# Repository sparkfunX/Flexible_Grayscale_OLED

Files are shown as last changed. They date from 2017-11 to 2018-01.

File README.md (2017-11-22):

SparkFun Carrier Board for Flexible Grayscale OLED Display
========================================

SparkFun Flexible Grayscale Carrier Board

[*SparkFun Flexible Grayscale Display - 1.81" (SPX-14543)*](https://www.sparkfun.com/products/14543)

This is a small flexible, grayscale OLED display. That’s right, we said flexible. We’ve been hearing about flexible displays for years, it’s finally here! You can’t fold it like paper but this OLED from Wisechip can be bent to a 40mm radius without damage. The display is than 0.5mm thick, less than 0.5 grams, and can display some impressive graphics with great contrast.

The carrier board generates the 12V required to drive the OLED display. The carrier board also has a signal buffer so that you can drive the display from any 3.3V or 5V microcontroller. However, because of the nature of the TXB0104 you must power the board with 3.5V or more. Your microcontroller can be 3.3V or 5V but we recommend you power the carrier board with 5V.

Repository Contents
-------------------

* **/Hardware** - Eagle design files (.brd, .sch)

Library
--------------
* **[Arduino Library](https://github.com/sparkfun/SparkFun_SSD1320_OLED_Arduino_Library)** - Library for drawing, graphics, text, etc.

License Information
-------------------

This product is _**open source**_! 

Please review the LICENSE.md file for license information. 

If you have any questions or concerns on licensing, please contact techsupport@sparkfun.com.

Please use, reuse, and modify these files as you see fit. Please maintain attribution to SparkFun Electronics and release anyThing Development Board derivative under the same license.

Distributed as-is; no warranty is given.

- Your friends at SparkFun.

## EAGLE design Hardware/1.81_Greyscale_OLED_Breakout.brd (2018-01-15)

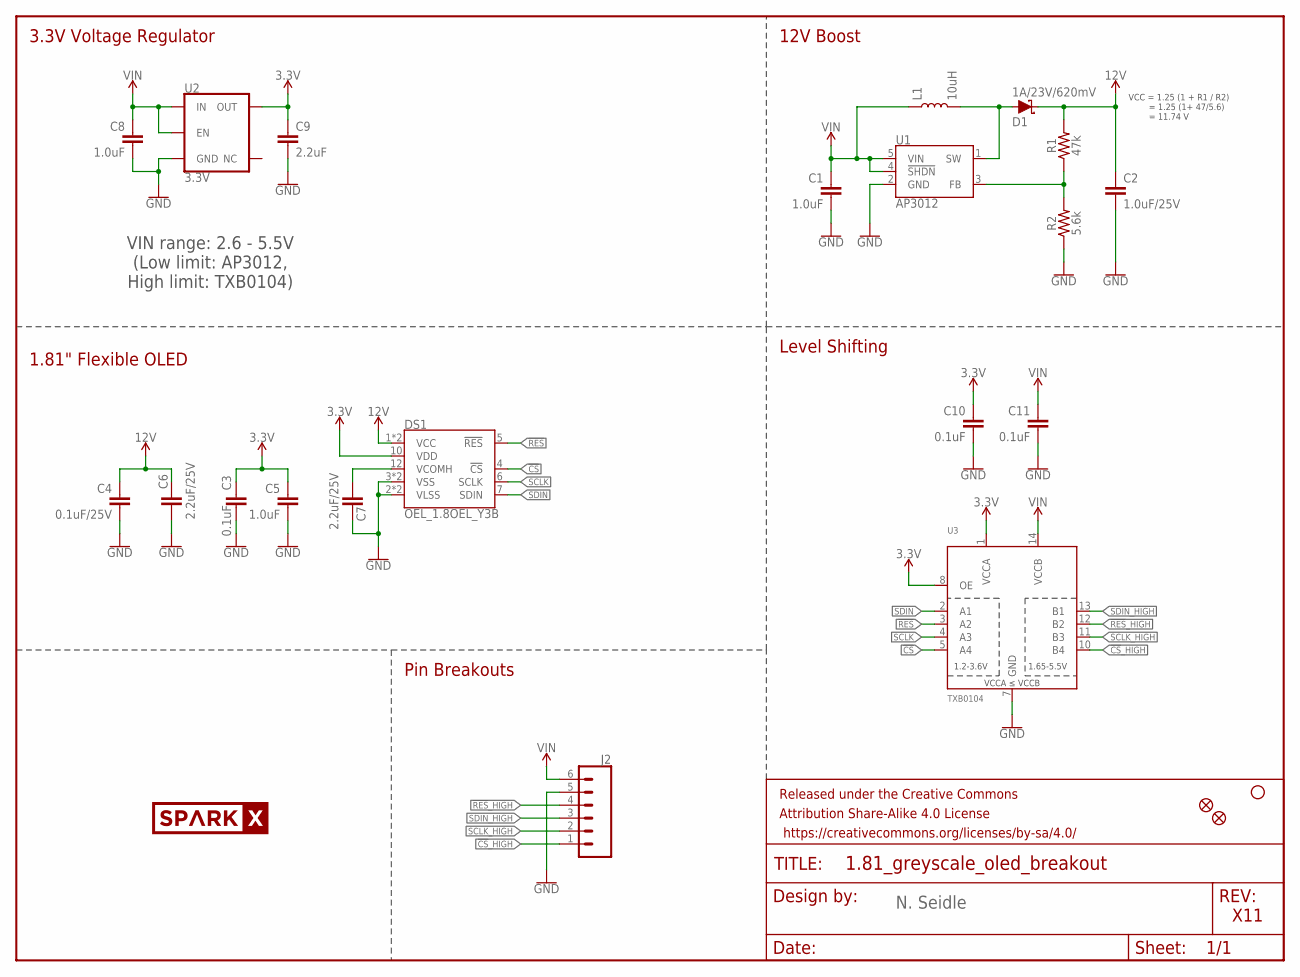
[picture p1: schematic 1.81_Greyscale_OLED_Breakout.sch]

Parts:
C1, C5, C8: 1.0uF; 0603
C2: 1.0uF/25V; 0805
C3, C10, C11: 0.1uF; 0603
C4: 0.1uF/25V; 0603
C6, C7: 2.2uF/25V; 0805
C9: 2.2uF; 0603
D1: 1A/23V/620mV; SOD-323
DS1: OEL_1.8OEL_Y3B; OEL_1.8_FPC_Y3B
FD1, FD2: FIDUCIAL1X2; FIDUCIAL-1X2
FRAME1: FRAME-LETTER; CREATIVE_COMMONS
H2: STAND-OFF
J2: CONN_06NO_SILK_NO_POP; 1X06_NO_SILK
L1: 10uH; INDUCTOR_3X3
LOGO1: SPARKX-LOGO5; SPARKX-LARGE
R1: 47k; 0603
R2: 5.6k; 0603
U1: AP3012; SOT23-5
U2: 3.3V; SOT23-5
U3: TXB0104; SO14

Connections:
3.3V: C3.1, C5.1, C9.1, C10.1, DS1.10 (VDD), U2.5 (OUT), U3.1 (VCCA), U3.8 (OE)
12V: C2.1, C4.1, C6.1, D1.C, DS1.1 (VCC), DS1.13 (VCC), R1.2
!CS!: DS1.4 (!CS!), U3.5 (A4)
!CS!_HIGH: J2.1, U3.10 (B4)
!RES!: DS1.5 (!RES!), U3.3 (A2)
!RES!_HIGH: J2.4, U3.12 (B2)
GND: C1.2, C2.2, C3.2, C4.2, C5.2, C6.2, C7.1, C8.2, C9.2, C10.2, C11.2, DS1.2 (VLSS), DS1.3 (VSS), DS1.8 (VSS), DS1.9 (VLSS), J2.5, R2.1, U1.2 (GND), U2.2 (GND), U3.7 (GND)
unnamed: C7.2, DS1.12 (VCOMH)
unnamed: D1.A, L1.P$2 (2), U1.1 (SW)
unnamed: R1.1, R2.2, U1.3 (FB)
SCLK: DS1.6 (SCLK), U3.4 (A3)
SCLK_HIGH: J2.2, U3.11 (B3)
SDIN: DS1.7 (SDIN), U3.2 (A1)
SDIN_HIGH: J2.3, U3.13 (B1)
VIN: C1.1, C8.1, C11.1, J2.6, L1.P$1 (1), U1.4 (!SHDN!), U1.5 (VIN), U2.1 (IN), U2.3 (EN), U3.14 (VCCB)

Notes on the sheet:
VCC = 1.25 (1 + R1 / R2) = 1.25 (1+ 47/5.6) = 11.74 V
VIN range: 2.6 - 5.5V (Low limit: AP3012, High limit: TXB0104)
3.3V Voltage Regulator
12V Boost
1.81" Flexible OLED
Level Shifting
Pin Breakouts
X11
N. Seidle

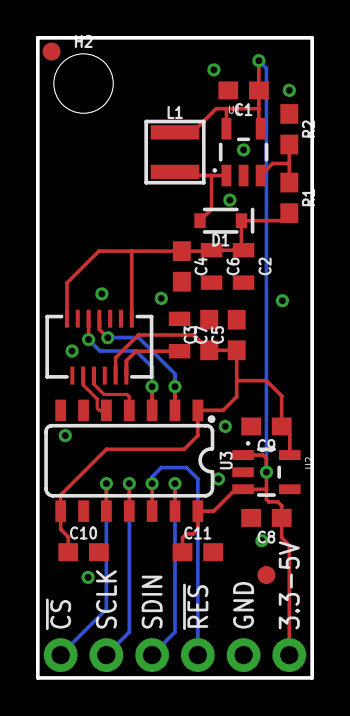
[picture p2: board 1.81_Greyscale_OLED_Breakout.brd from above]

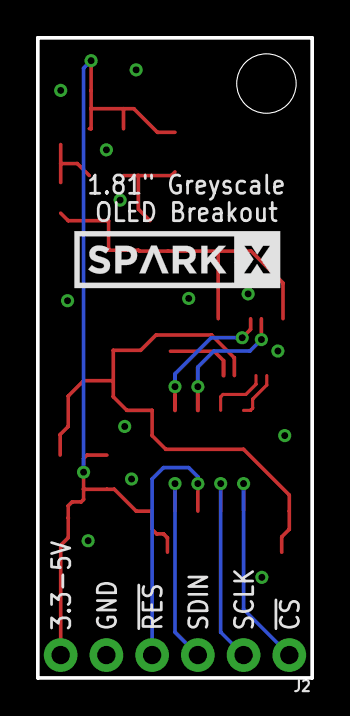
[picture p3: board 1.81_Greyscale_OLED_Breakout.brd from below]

Board: 2 copper layers, 15.2 x 35.6 mm, 25 parts (3 on the bottom side), 15 nets.

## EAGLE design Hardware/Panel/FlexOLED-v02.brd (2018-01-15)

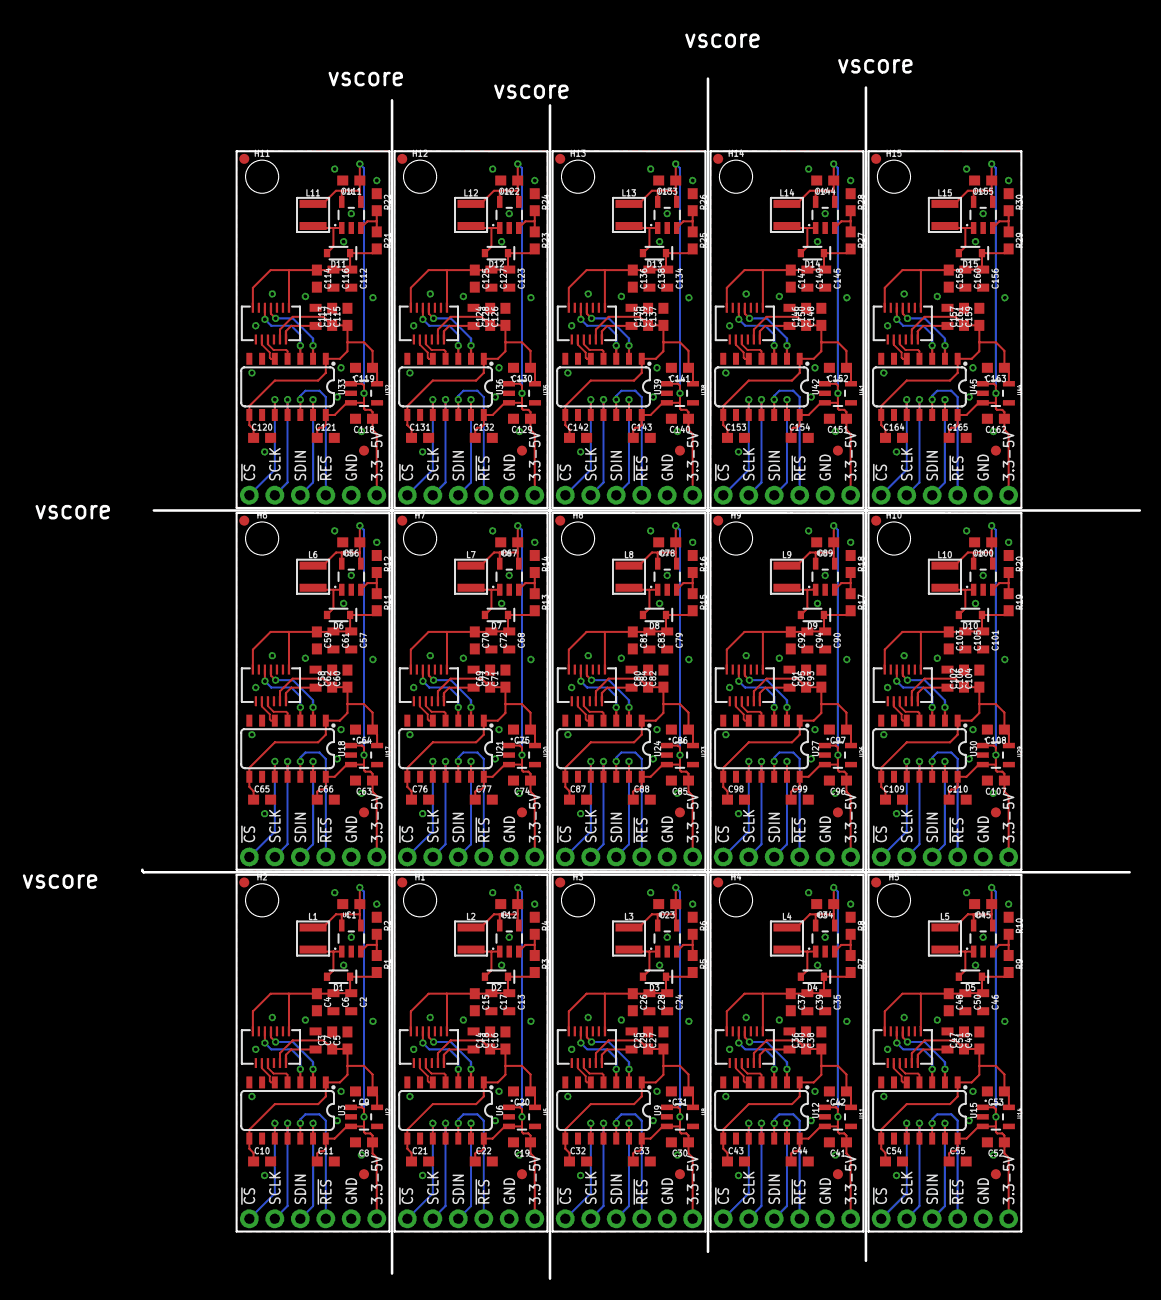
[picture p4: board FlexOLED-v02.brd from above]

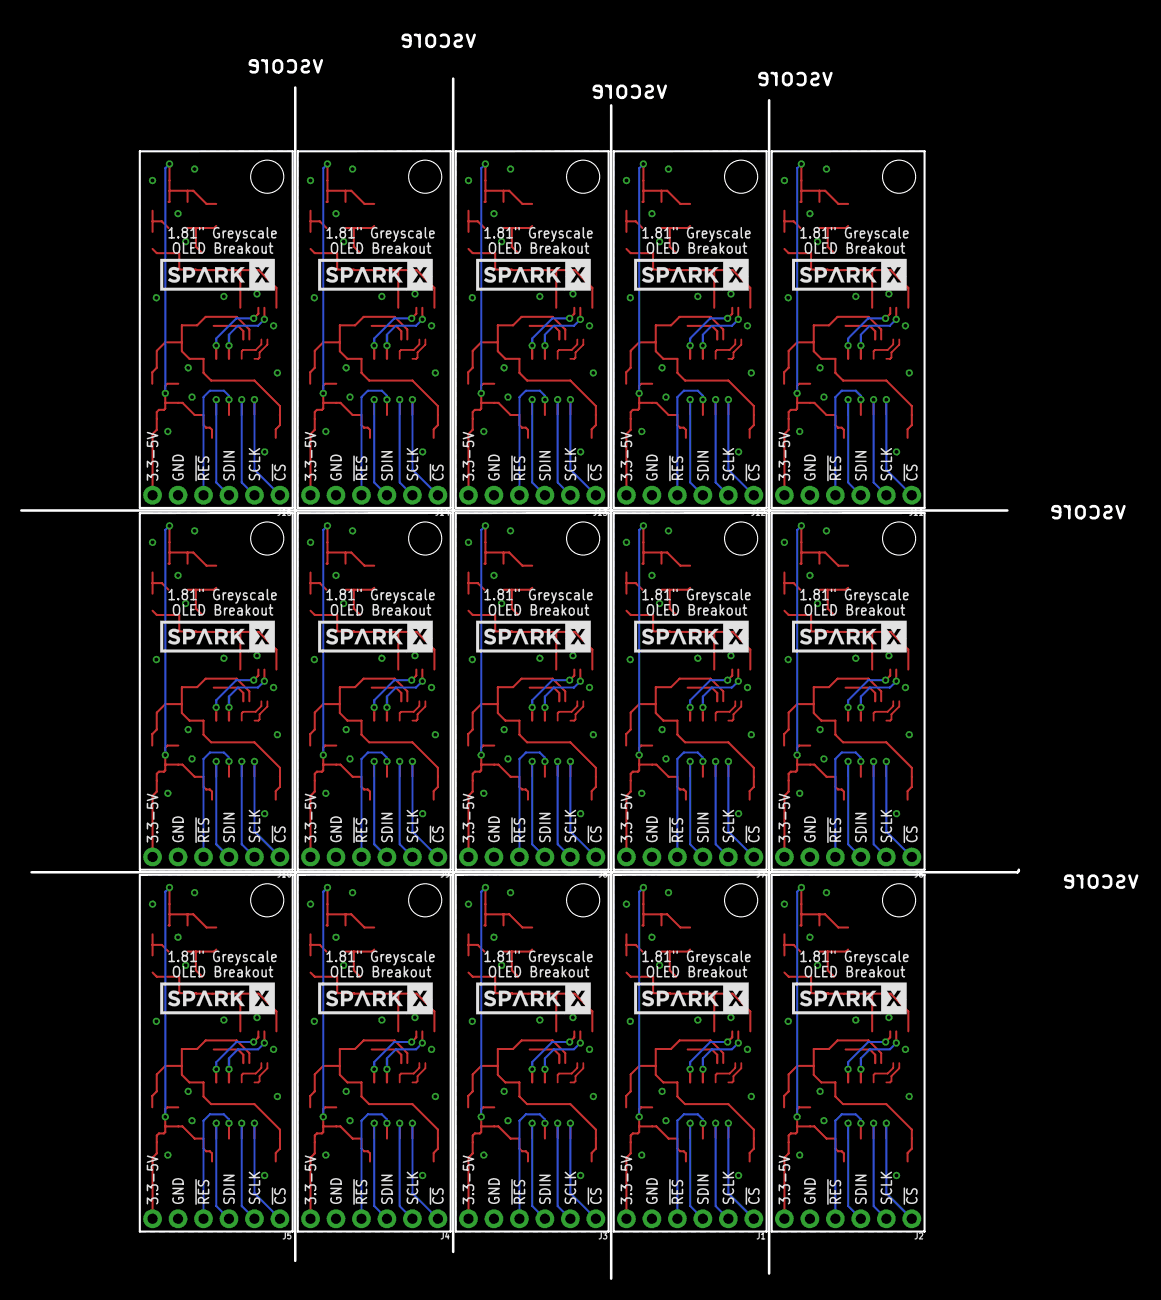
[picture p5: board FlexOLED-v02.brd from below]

Board: 2 copper layers, 99.4 x 119.6 mm, 360 parts (45 on the bottom side), 225 nets.

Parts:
C1, C5, C8, C12, C16, C19, C23, C27, C30, C34, C38, C41, C45, C49, C52, C56, C60, C63, C67, C71, C74, C78, C82, C85, C89, C93, C96, C100, C104, C107, C111, C115, C118, C122, C126, C129, C133, C137, C140, C144, C148, C151, C155, C159, C162: 1.0uF; 0603
C2, C13, C24, C35, C46, C57, C68, C79, C90, C101, C112, C123, C134, C145, C156: 1.0uF/25V; 0805
C3, C10, C11, C14, C21, C22, C25, C32, C33, C36, C43, C44, C47, C54, C55, C58, C65, C66, C69, C76, C77, C80, C87, C88, C91, C98, C99, C102, C109, C110, C113, C120, C121, C124, C131, C132, C135, C142, C143, C146, C153, C154, C157, C164, C165: 0.1uF; 0603
C4, C15, C26, C37, C48, C59, C70, C81, C92, C103, C114, C125, C136, C147, C158: 0.1uF/25V; 0603
C6, C7, C17, C18, C28, C29, C39, C40, C50, C51, C61, C62, C72, C73, C83, C84, C94, C95, C105, C106, C116, C117, C127, C128, C138, C139, C149, C150, C160, C161: 2.2uF/25V; 0805
C9, C20, C31, C42, C53, C64, C75, C86, C97, C108, C119, C130, C141, C152, C163: 2.2uF; 0603
D1, D2, D3, D4, D5, D6, D7, D8, D9, D10, D11, D12, D13, D14, D15: 1A/23V/620mV; SOD-323
DS1, DS2, DS3, DS4, DS5, DS6, DS7, DS8, DS9, DS10, DS11, DS12, DS13, DS14, DS15: OEL_1.8OEL_Y3B; OEL_1.8_FPC_Y3B
FD1, FD2, FD3, FD4, FD5, FD6, FD7, FD8, FD9, FD10, FD11, FD12, FD13, FD14, FD15, FD16, FD17, FD18, FD19, FD20, FD21, FD22, FD23, FD24, FD25, FD26, FD27, FD28, FD29, FD30: FIDUCIAL1X2; FIDUCIAL-1X2
H1, H2, H3, H4, H5, H6, H7, H8, H9, H10, H11, H12, H13, H14, H15: STAND-OFF
J1, J2, J3, J4, J5, J6, J7, J8, J9, J10, J11, J12, J13, J14, J15: 1X06_NO_SILK
L1, L2, L3, L4, L5, L6, L7, L8, L9, L10, L11, L12, L13, L14, L15: 10uH; INDUCTOR_3X3
LOGO1, LOGO2, LOGO3, LOGO4, LOGO5, LOGO6, LOGO7, LOGO8, LOGO9, LOGO10, LOGO11, LOGO12, LOGO13, LOGO14, LOGO15: SPARKX-LOGO5; SPARKX-LARGE
R1, R3, R5, R7, R9, R11, R13, R15, R17, R19, R21, R23, R25, R27, R29: 47k; 0603
R2, R4, R6, R8, R10, R12, R14, R16, R18, R20, R22, R24, R26, R28, R30: 5.6k; 0603
U1, U4, U7, U10, U13, U16, U19, U22, U25, U28, U31, U34, U37, U40, U43: AP3012; SOT23-5
U2, U5, U8, U11, U14, U17, U20, U23, U26, U29, U32, U35, U38, U41, U44: 3.3V; SOT23-5
U3, U6, U9, U12, U15, U18, U21, U24, U27, U30, U33, U36, U39, U42, U45: TXB0104; SO14

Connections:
3.3V: C3.1, C5.1, C9.1, C10.1, DS1.10, U2.5, U3.1, U3.8
3.3V1: C14.1, C16.1, C20.1, C21.1, DS2.10, U5.5, U6.1, U6.8
3.3V2: C25.1, C27.1, C31.1, C32.1, DS3.10, U8.5, U9.1, U9.8
3.3V3: C36.1, C38.1, C42.1, C43.1, DS4.10, U11.5, U12.1, U12.8
3.3V4: C47.1, C49.1, C53.1, C54.1, DS5.10, U14.5, U15.1, U15.8
3.3V5: C58.1, C60.1, C64.1, C65.1, DS6.10, U17.5, U18.1, U18.8
3.3V6: C69.1, C71.1, C75.1, C76.1, DS7.10, U20.5, U21.1, U21.8
3.3V7: C80.1, C82.1, C86.1, C87.1, DS8.10, U23.5, U24.1, U24.8
3.3V8: C91.1, C93.1, C97.1, C98.1, DS9.10, U26.5, U27.1, U27.8
3.3V9: C102.1, C104.1, C108.1, C109.1, DS10.10, U29.5, U30.1, U30.8
3.3V10: C113.1, C115.1, C119.1, C120.1, DS11.10, U32.5, U33.1, U33.8
3.3V11: C124.1, C126.1, C130.1, C131.1, DS12.10, U35.5, U36.1, U36.8
3.3V12: C135.1, C137.1, C141.1, C142.1, DS13.10, U38.5, U39.1, U39.8
3.3V13: C146.1, C148.1, C152.1, C153.1, DS14.10, U41.5, U42.1, U42.8
3.3V14: C157.1, C159.1, C163.1, C164.1, DS15.10, U44.5, U45.1, U45.8
12V: C2.1, C4.1, C6.1, D1.C, DS1.1, DS1.13, R1.2
12V1: C13.1, C15.1, C17.1, D2.C, DS2.1, DS2.13, R3.2
12V2: C24.1, C26.1, C28.1, D3.C, DS3.1, DS3.13, R5.2
12V3: C35.1, C37.1, C39.1, D4.C, DS4.1, DS4.13, R7.2
12V4: C46.1, C48.1, C50.1, D5.C, DS5.1, DS5.13, R9.2
12V5: C57.1, C59.1, C61.1, D6.C, DS6.1, DS6.13, R11.2
12V6: C68.1, C70.1, C72.1, D7.C, DS7.1, DS7.13, R13.2
12V7: C79.1, C81.1, C83.1, D8.C, DS8.1, DS8.13, R15.2
12V8: C90.1, C92.1, C94.1, D9.C, DS9.1, DS9.13, R17.2
12V9: C101.1, C103.1, C105.1, D10.C, DS10.1, DS10.13, R19.2
12V10: C112.1, C114.1, C116.1, D11.C, DS11.1, DS11.13, R21.2
12V11: C123.1, C125.1, C127.1, D12.C, DS12.1, DS12.13, R23.2
12V12: C134.1, C136.1, C138.1, D13.C, DS13.1, DS13.13, R25.2
12V13: C145.1, C147.1, C149.1, D14.C, DS14.1, DS14.13, R27.2
12V14: C156.1, C158.1, C160.1, D15.C, DS15.1, DS15.13, R29.2
!CS!: DS1.4, U3.5
!CS!1: DS2.4, U6.5
!CS!2: DS3.4, U9.5
!CS!3: DS4.4, U12.5
!CS!4: DS5.4, U15.5
!CS!5: DS6.4, U18.5
!CS!6: DS7.4, U21.5
!CS!7: DS8.4, U24.5
!CS!8: DS9.4, U27.5
!CS!9: DS10.4, U30.5
!CS!10: DS11.4, U33.5
!CS!11: DS12.4, U36.5
!CS!12: DS13.4, U39.5
!CS!13: DS14.4, U42.5
!CS!14: DS15.4, U45.5
!CS!_HIGH: J2.1, U3.10
!CS!_HIGH1: J1.1, U6.10
!CS!_HIGH2: J3.1, U9.10
!CS!_HIGH3: J4.1, U12.10
!CS!_HIGH4: J5.1, U15.10
!CS!_HIGH5: J6.1, U18.10
!CS!_HIGH6: J7.1, U21.10
!CS!_HIGH7: J8.1, U24.10
!CS!_HIGH8: J9.1, U27.10
!CS!_HIGH9: J10.1, U30.10
!CS!_HIGH10: J11.1, U33.10
!CS!_HIGH11: J12.1, U36.10
!CS!_HIGH12: J13.1, U39.10
!CS!_HIGH13: J14.1, U42.10
!CS!_HIGH14: J15.1, U45.10
!RES!: DS1.5, U3.3
!RES!1: DS2.5, U6.3
!RES!2: DS3.5, U9.3
!RES!3: DS4.5, U12.3
!RES!4: DS5.5, U15.3
!RES!5: DS6.5, U18.3
!RES!6: DS7.5, U21.3
!RES!7: DS8.5, U24.3
!RES!8: DS9.5, U27.3
!RES!9: DS10.5, U30.3
!RES!10: DS11.5, U33.3
!RES!11: DS12.5, U36.3
!RES!12: DS13.5, U39.3
!RES!13: DS14.5, U42.3
!RES!14: DS15.5, U45.3
!RES!_HIGH: J2.4, U3.12
!RES!_HIGH1: J1.4, U6.12
!RES!_HIGH2: J3.4, U9.12
!RES!_HIGH3: J4.4, U12.12
!RES!_HIGH4: J5.4, U15.12
!RES!_HIGH5: J6.4, U18.12
!RES!_HIGH6: J7.4, U21.12
!RES!_HIGH7: J8.4, U24.12
!RES!_HIGH8: J9.4, U27.12
!RES!_HIGH9: J10.4, U30.12
!RES!_HIGH10: J11.4, U33.12
!RES!_HIGH11: J12.4, U36.12
!RES!_HIGH12: J13.4, U39.12
!RES!_HIGH13: J14.4, U42.12
!RES!_HIGH14: J15.4, U45.12
GND: C1.2, C2.2, C3.2, C4.2, C5.2, C6.2, C7.1, C8.2, C9.2, C10.2, C11.2, DS1.2, DS1.3, DS1.8, DS1.9, J2.5, R2.1, U1.2, U2.2, U3.7
GND1: C12.2, C13.2, C14.2, C15.2, C16.2, C17.2, C18.1, C19.2, C20.2, C21.2, C22.2, DS2.2, DS2.3, DS2.8, DS2.9, J1.5, R4.1, U4.2, U5.2, U6.7
GND2: C23.2, C24.2, C25.2, C26.2, C27.2, C28.2, C29.1, C30.2, C31.2, C32.2, C33.2, DS3.2, DS3.3, DS3.8, DS3.9, J3.5, R6.1, U7.2, U8.2, U9.7
GND3: C34.2, C35.2, C36.2, C37.2, C38.2, C39.2, C40.1, C41.2, C42.2, C43.2, C44.2, DS4.2, DS4.3, DS4.8, DS4.9, J4.5, R8.1, U10.2, U11.2, U12.7
GND4: C45.2, C46.2, C47.2, C48.2, C49.2, C50.2, C51.1, C52.2, C53.2, C54.2, C55.2, DS5.2, DS5.3, DS5.8, DS5.9, J5.5, R10.1, U13.2, U14.2, U15.7
GND5: C56.2, C57.2, C58.2, C59.2, C60.2, C61.2, C62.1, C63.2, C64.2, C65.2, C66.2, DS6.2, DS6.3, DS6.8, DS6.9, J6.5, R12.1, U16.2, U17.2, U18.7
GND6: C67.2, C68.2, C69.2, C70.2, C71.2, C72.2, C73.1, C74.2, C75.2, C76.2, C77.2, DS7.2, DS7.3, DS7.8, DS7.9, J7.5, R14.1, U19.2, U20.2, U21.7
GND7: C78.2, C79.2, C80.2, C81.2, C82.2, C83.2, C84.1, C85.2, C86.2, C87.2, C88.2, DS8.2, DS8.3, DS8.8, DS8.9, J8.5, R16.1, U22.2, U23.2, U24.7
GND8: C89.2, C90.2, C91.2, C92.2, C93.2, C94.2, C95.1, C96.2, C97.2, C98.2, C99.2, DS9.2, DS9.3, DS9.8, DS9.9, J9.5, R18.1, U25.2, U26.2, U27.7
GND9: C100.2, C101.2, C102.2, C103.2, C104.2, C105.2, C106.1, C107.2, C108.2, C109.2, C110.2, DS10.2, DS10.3, DS10.8, DS10.9, J10.5, R20.1, U28.2, U29.2, U30.7
GND10: C111.2, C112.2, C113.2, C114.2, C115.2, C116.2, C117.1, C118.2, C119.2, C120.2, C121.2, DS11.2, DS11.3, DS11.8, DS11.9, J11.5, R22.1, U31.2, U32.2, U33.7
GND12: C122.2, C123.2, C124.2, C125.2, C126.2, C127.2, C128.1, C129.2, C130.2, C131.2, C132.2, DS12.2, DS12.3, DS12.8, DS12.9, J12.5, R24.1, U34.2, U35.2, U36.7
GND13: C133.2, C134.2, C135.2, C136.2, C137.2, C138.2, C139.1, C140.2, C141.2, C142.2, C143.2, DS13.2, DS13.3, DS13.8, DS13.9, J13.5, R26.1, U37.2, U38.2, U39.7
GND14: C144.2, C145.2, C146.2, C147.2, C148.2, C149.2, C150.1, C151.2, C152.2, C153.2, C154.2, DS14.2, DS14.3, DS14.8, DS14.9, J14.5, R28.1, U40.2, U41.2, U42.7
GND15: C155.2, C156.2, C157.2, C158.2, C159.2, C160.2, C161.1, C162.2, C163.2, C164.2, C165.2, DS15.2, DS15.3, DS15.8, DS15.9, J15.5, R30.1, U43.2, U44.2, U45.7
unnamed: C7.2, DS1.12
unnamed: D1.A, L1.P$2, U1.1
unnamed: R1.1, R2.2, U1.3
unnamed: D2.A, L2.P$2, U4.1
unnamed: R3.1, R4.2, U4.3
unnamed: C18.2, DS2.12
unnamed: D3.A, L3.P$2, U7.1
unnamed: R5.1, R6.2, U7.3
unnamed: C29.2, DS3.12
unnamed: D4.A, L4.P$2, U10.1
unnamed: R7.1, R8.2, U10.3
unnamed: C40.2, DS4.12
unnamed: D5.A, L5.P$2, U13.1
unnamed: R9.1, R10.2, U13.3
unnamed: C51.2, DS5.12
unnamed: D6.A, L6.P$2, U16.1
unnamed: R11.1, R12.2, U16.3
unnamed: C62.2, DS6.12
unnamed: D7.A, L7.P$2, U19.1
unnamed: R13.1, R14.2, U19.3
unnamed: C73.2, DS7.12
unnamed: D8.A, L8.P$2, U22.1
unnamed: R15.1, R16.2, U22.3
unnamed: C84.2, DS8.12
unnamed: D9.A, L9.P$2, U25.1
unnamed: R17.1, R18.2, U25.3
unnamed: C95.2, DS9.12
unnamed: D10.A, L10.P$2, U28.1
unnamed: R19.1, R20.2, U28.3
unnamed: C106.2, DS10.12
unnamed: D11.A, L11.P$2, U31.1
unnamed: R21.1, R22.2, U31.3
unnamed: C117.2, DS11.12
unnamed: D12.A, L12.P$2, U34.1
unnamed: R23.1, R24.2, U34.3
unnamed: C128.2, DS12.12
unnamed: D13.A, L13.P$2, U37.1
unnamed: R25.1, R26.2, U37.3
unnamed: C139.2, DS13.12
unnamed: D14.A, L14.P$2, U40.1
unnamed: R27.1, R28.2, U40.3
unnamed: C150.2, DS14.12
unnamed: D15.A, L15.P$2, U43.1
unnamed: R29.1, R30.2, U43.3
unnamed: C161.2, DS15.12
SCLK: DS1.6, U3.4
SCLK1: DS2.6, U6.4
SCLK2: DS3.6, U9.4
SCLK3: DS4.6, U12.4
SCLK4: DS5.6, U15.4
SCLK5: DS6.6, U18.4
SCLK6: DS7.6, U21.4
SCLK7: DS8.6, U24.4
SCLK8: DS9.6, U27.4
SCLK9: DS10.6, U30.4
SCLK10: DS11.6, U33.4
SCLK11: DS12.6, U36.4
SCLK12: DS13.6, U39.4
SCLK13: DS14.6, U42.4
SCLK14: DS15.6, U45.4
SCLK_HIGH: J2.2, U3.11
SCLK_HIGH1: J1.2, U6.11
SCLK_HIGH2: J3.2, U9.11
SCLK_HIGH3: J4.2, U12.11
SCLK_HIGH4: J5.2, U15.11
SCLK_HIGH5: J6.2, U18.11
SCLK_HIGH6: J7.2, U21.11
SCLK_HIGH7: J8.2, U24.11
SCLK_HIGH8: J9.2, U27.11
SCLK_HIGH9: J10.2, U30.11
SCLK_HIGH10: J11.2, U33.11
SCLK_HIGH11: J12.2, U36.11
SCLK_HIGH12: J13.2, U39.11
SCLK_HIGH13: J14.2, U42.11
SCLK_HIGH14: J15.2, U45.11
SDIN: DS1.7, U3.2
SDIN1: DS2.7, U6.2
SDIN2: DS3.7, U9.2
SDIN3: DS4.7, U12.2
SDIN4: DS5.7, U15.2
SDIN5: DS6.7, U18.2
SDIN6: DS7.7, U21.2
SDIN7: DS8.7, U24.2
SDIN8: DS9.7, U27.2
SDIN9: DS10.7, U30.2
SDIN10: DS11.7, U33.2
SDIN11: DS12.7, U36.2
SDIN12: DS13.7, U39.2
SDIN13: DS14.7, U42.2
SDIN14: DS15.7, U45.2
SDIN_HIGH: J2.3, U3.13
SDIN_HIGH1: J1.3, U6.13
SDIN_HIGH2: J3.3, U9.13
SDIN_HIGH3: J4.3, U12.13
SDIN_HIGH4: J5.3, U15.13
SDIN_HIGH5: J6.3, U18.13
SDIN_HIGH6: J7.3, U21.13
SDIN_HIGH7: J8.3, U24.13
SDIN_HIGH8: J9.3, U27.13
SDIN_HIGH9: J10.3, U30.13
SDIN_HIGH10: J11.3, U33.13
SDIN_HIGH11: J12.3, U36.13
SDIN_HIGH12: J13.3, U39.13
SDIN_HIGH13: J14.3, U42.13
SDIN_HIGH14: J15.3, U45.13
VIN: C1.1, C8.1, C11.1, J2.6, L1.P$1, U1.4, U1.5, U2.1, U2.3, U3.14
VIN1: C12.1, C19.1, C22.1, J1.6, L2.P$1, U4.4, U4.5, U5.1, U5.3, U6.14
VIN2: C23.1, C30.1, C33.1, J3.6, L3.P$1, U7.4, U7.5, U8.1, U8.3, U9.14
VIN3: C34.1, C41.1, C44.1, J4.6, L4.P$1, U10.4, U10.5, U11.1, U11.3, U12.14
VIN4: C45.1, C52.1, C55.1, J5.6, L5.P$1, U13.4, U13.5, U14.1, U14.3, U15.14
VIN5: C56.1, C63.1, C66.1, J6.6, L6.P$1, U16.4, U16.5, U17.1, U17.3, U18.14
VIN6: C67.1, C74.1, C77.1, J7.6, L7.P$1, U19.4, U19.5, U20.1, U20.3, U21.14
VIN7: C78.1, C85.1, C88.1, J8.6, L8.P$1, U22.4, U22.5, U23.1, U23.3, U24.14
VIN8: C89.1, C96.1, C99.1, J9.6, L9.P$1, U25.4, U25.5, U26.1, U26.3, U27.14
VIN9: C100.1, C107.1, C110.1, J10.6, L10.P$1, U28.4, U28.5, U29.1, U29.3, U30.14
VIN10: C111.1, C118.1, C121.1, J11.6, L11.P$1, U31.4, U31.5, U32.1, U32.3, U33.14
VIN11: C122.1, C129.1, C132.1, J12.6, L12.P$1, U34.4, U34.5, U35.1, U35.3, U36.14
VIN12: C133.1, C140.1, C143.1, J13.6, L13.P$1, U37.4, U37.5, U38.1, U38.3, U39.14
VIN13: C144.1, C151.1, C154.1, J14.6, L14.P$1, U40.4, U40.5, U41.1, U41.3, U42.14
VIN14: C155.1, C162.1, C165.1, J15.6, L15.P$1, U43.4, U43.5, U44.1, U44.3, U45.14

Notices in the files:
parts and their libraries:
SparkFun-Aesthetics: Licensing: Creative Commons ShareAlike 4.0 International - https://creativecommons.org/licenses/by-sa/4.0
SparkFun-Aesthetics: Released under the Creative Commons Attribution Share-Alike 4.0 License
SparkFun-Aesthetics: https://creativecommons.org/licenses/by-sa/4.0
